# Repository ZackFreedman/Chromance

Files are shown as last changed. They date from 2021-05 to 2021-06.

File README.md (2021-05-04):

# Chromance
Big, bold rainbow-glowing wall art that features the king of shapes - the hexagon. 
This project was designed to work with an EmotiBit wristband to display biometric data, but it doesn't need one!
A gorgeous animated ripple effect will automatically kick in after just a few seconds.

Project video: https://www.youtube.com/watch?v=g6n8XLmZ__I

Instructions: https://voidstar.dozuki.com/Guide/Chromance+Assembly+Instructions/6
(PDF in the repo may be out of date)

The following information is for my configuration. Feel free to build your own - the code is very easy to edit to accommodate yours

Bill of materials:
* 10m LED channel w/ white diffuser, pref. black - https://amzn.to/3nFEC3w
* 10m DotStar LED tape, 60 pixels/m - https://www.adafruit.com/product/2239?length=4
	* OR: 10m WS2812B (NeoPixel) LED tape, 60 pixels/m - https://amzn.to/3gTGzYS
* 1x Node32S-style ESP32 module - https://amzn.to/2QO9brO
* 2.54mm headers - https://amzn.to/3ujX4S0
* 1x 8-position 2.54mm-pitch terminal - https://amzn.to/3uerfKd
* 1x 2-position 5mm-pitch terminal - https://amzn.to/3gU5WJV
* 1x 2.1mm barrel jack, PCB mount - https://amzn.to/33bmpRS
* Stripboard - https://amzn.to/3aXs2Yc
* Epoxy (I like JB Kwik-Weld) - https://amzn.to/3xHL1jp
* 5V PSU w/ 2.1mm barrel plug 5A or higher - https://amzn.to/2RkIL0A
* 1/2" wide double stick tape, at least 3m - https://amzn.to/3gT8mst
* 3D printer filament - I used carbon-fiber PLA - https://amzn.to/3xHIwh6
* Lots of wire, solder, and flux
* Hot glue

**These affiliate links support future projects and the videos about them!**

3D print list:
- 1x TopLeftNode.stl
- 1x TopRightNode.stl
- 3x TopCenterNode.stl
- 20x RegularNode.stl

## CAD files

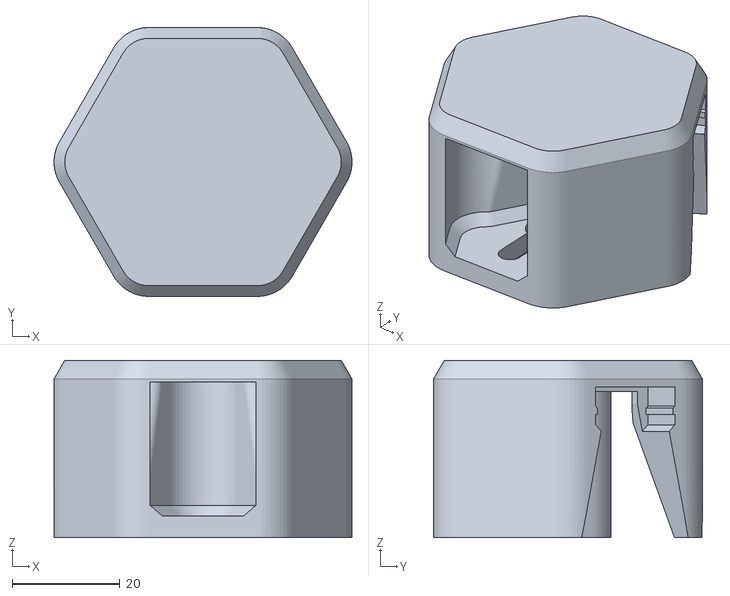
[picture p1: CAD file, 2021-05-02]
STL's/TopCenterNode.stl
55.4 x 50.0 x 33.0

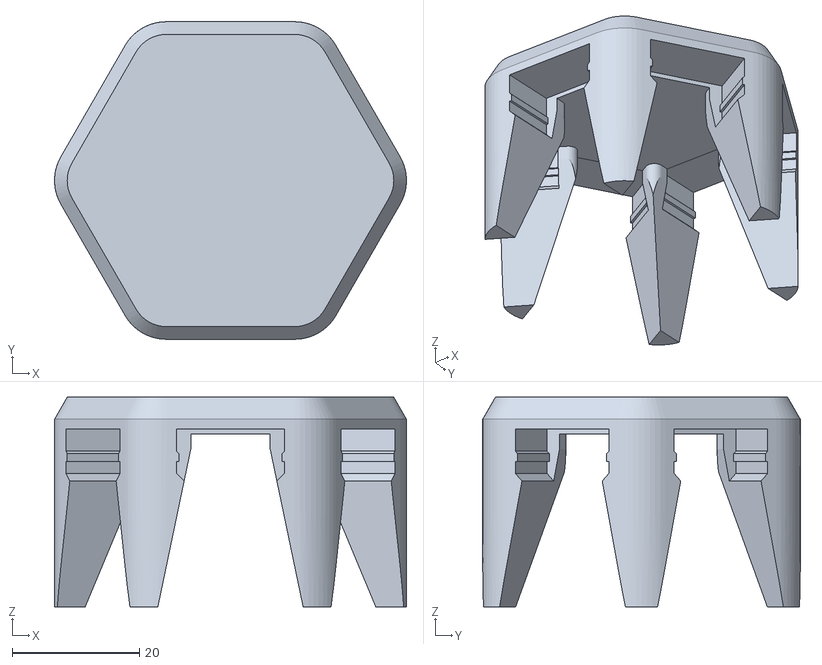
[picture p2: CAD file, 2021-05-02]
STL's/RegularNode.stl
55.4 x 50.0 x 33.0

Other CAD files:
STL's/TopLeftNode.stl
STL's/TopRightNode.stl
Models/RegularNode.f3d
Models/TopCenterNode.f3d
Models/TopLeftNode.f3d
Models/TopRightNode.f3d

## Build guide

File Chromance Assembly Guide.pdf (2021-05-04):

# Voidstar Lab

# Chromance Assembly Instructions

Build your own glowing rainbow wall hexagons - and maybe even link them with your biometrics!

## Written By: Zack Freedman

Chromance Assembly Instructions | Guide ID: 6 - Draft: 2021-05-03

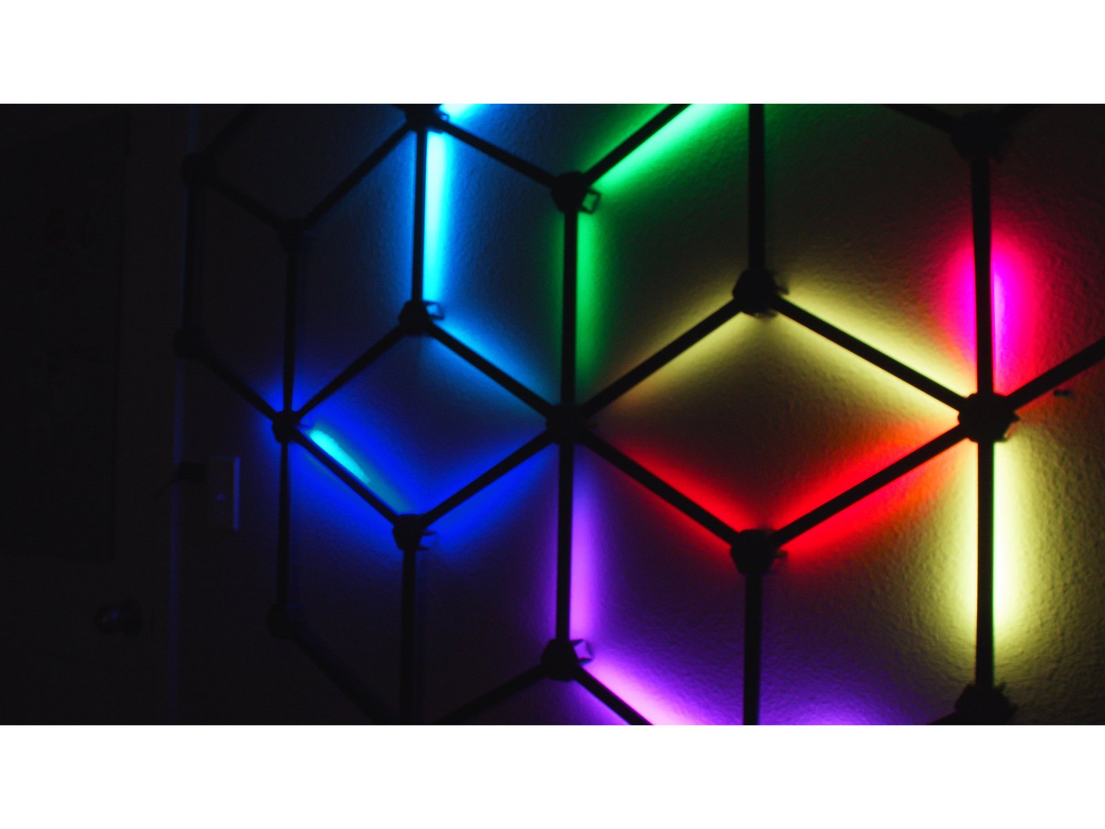
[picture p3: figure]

This document was generated on 2021-05-03 05:29:10 PM (MST).

© 2021 | voidstar.dozuki.com/ | Page 1 of 16

### INTRODUCTION

Turn your most boring wall into a big statement with this lavishly illuminated RGB decoration. It's easy to assemble and looks phenomenal - and if you have an EmotiBit, it'll even visualize your heartbeats and sweat spikes in perfectly synchronized pulses.

Watch the video: https://www.youtube.com/watch?v=g6n8XLmZ... (https://www.youtube.com/watch?v=g6n8XLmZ__I)

Download the firmware: https://github.com/ZackFreedman/Chromanc...

Grab the STL's: https://thangs.com/ZackFreedman/Chromanc...

Bill of Materials:

10m LED channel w/ white diffuser, pref. black - https://amzn.to/3nFEC3w
10m DotStar LED tape, 60 pixels/m - https://www.adafruit.com/product/2239?le... (https://www.adafruit.com/product/2239?length=4) OR: 10m WS2812B (NeoPixel) LED tape, 60 pixels/m - https://amzn.to/3gTGzYS 1x Node32S-style ESP32 module - https://amzn.to/2QO9brO
2.54mm headers - https://amzn.to/3ujX4S0
1x 8-position 2.54mm-pitch terminal - https://amzn.to/3uerfKd
1x 2-position 5mm-pitch terminal - https://amzn.to/3gU5WJV 1x 2.1mm barrel jack, PCB mount - https://amzn.to/33bmpRS Stripboard - https://amzn.to/3aXs2Yc
Epoxy (I like JB Kwik-Weld) - https://amzn.to/3xHL1jp
5V PSU w/ 2.1mm barrel plug 5A or higher - https://amzn.to/2RkIL0A1/2" wide double stick tape, at least 3m - https://amzn.to/3gT8mst
3D printer filament - I used carbon-fiber PLA - https://amzn.to/3xHIwh6 Lots of wire, solder, and flux
Hot glue

Step 1 — Start Printing

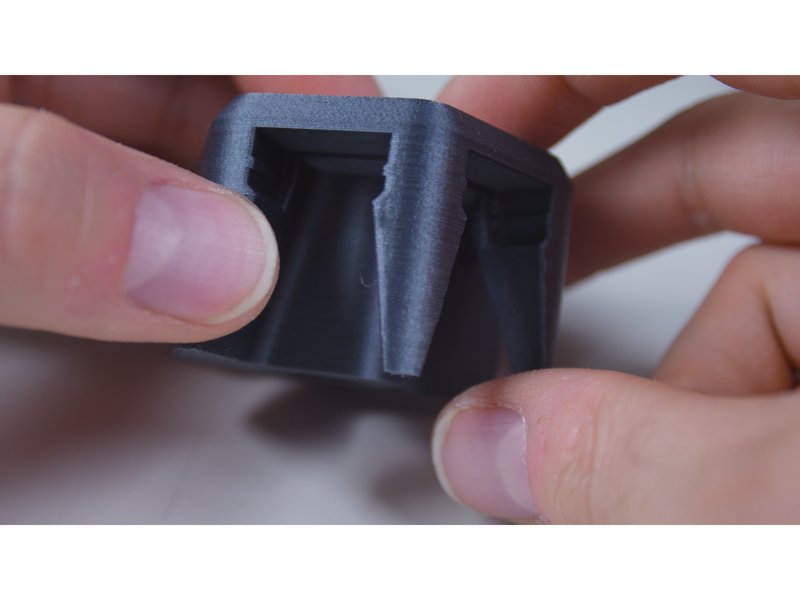
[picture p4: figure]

- Print the following:
- 1x TopLeftNode.stl
- 1x TopRightNode.stl
- 3x TopCenterNode.stl
- 20x RegularNode.stl

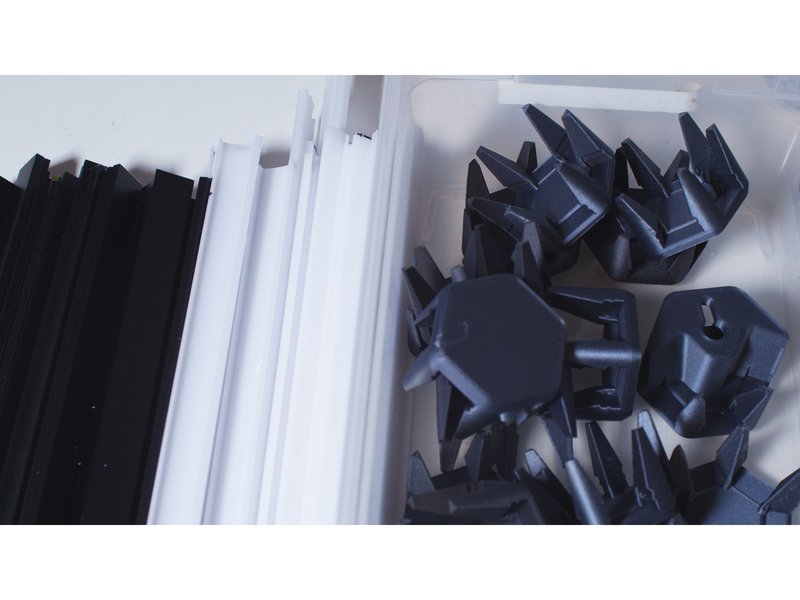
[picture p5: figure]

- I used carbon fiber PLA. Nail that first layer - it's what people will see.

The Top nodes must be printed with supports everywhere. The Regular nodes do not need supports.

Step 2 — Prep for Segments
- Cut 40 segments of LED strips, 14 LED's long.
- Don't cut off too much of the pads on the ends! We need to solder to it!

Cut 40 segments of aluminum extrusion, 25cm each. Deburr the ends so they don't cut into the strips!

- Cut 40 segments of diffuser plastic, 23cm each.

The diffusers should be shorter than the aluminum, or they'll be difficult to snap onto the extrusion after the system is assembled.

Step 3 — Assemble the Strips

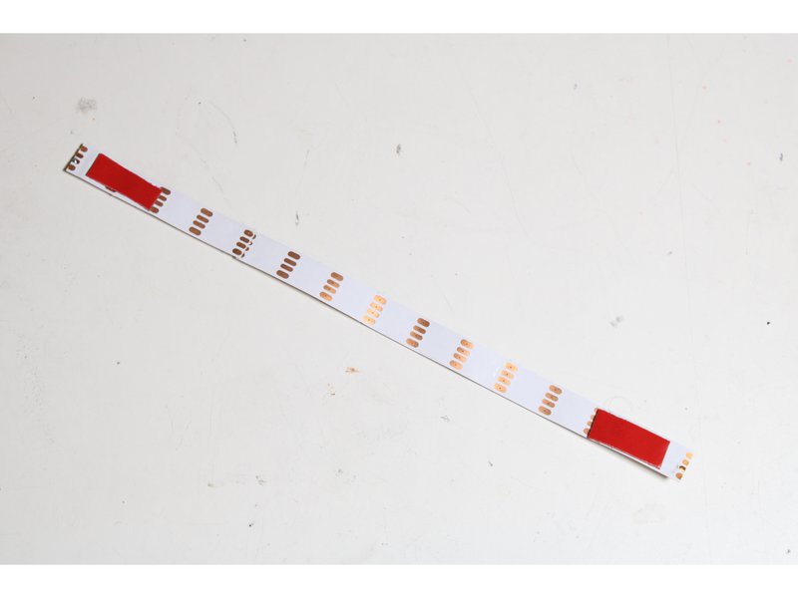
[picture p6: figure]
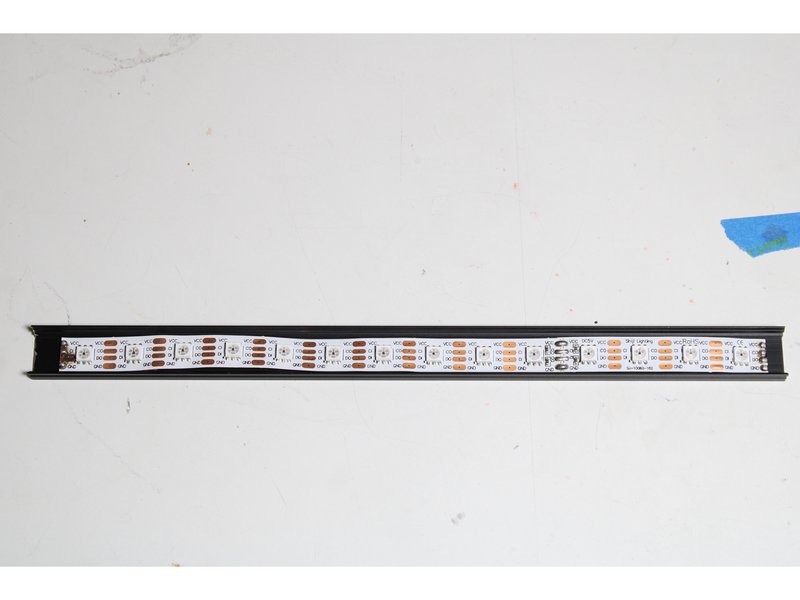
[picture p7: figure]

Use some heat-tolerant double-stick tape to mount a strip to the center of each aluminum segment.

- Don't put tape too close to the ends! It'll burn when we solder the strips!

The tape may not be necessary if your strips are particularly wide. If the channel in the extrusion holds the strip securely on its own, no tape is needed.

Step 4 — Pre-Assembly

Assemble the network - but don't glue it yet! Remember that the node names are backwards, because this is sitting upside-down.

- TopRightNode goes here.
- TopCenterNodes go here
- TopLeftNode goes here
- All other nodes are RegularNodes.

Make sure the strips face the directions indicated. There should be arrows on the strips, but if there aren't, the pads named DI and CI are the start of the strips, and DO and CO are the end.

Step 5 — Permanent Assembly

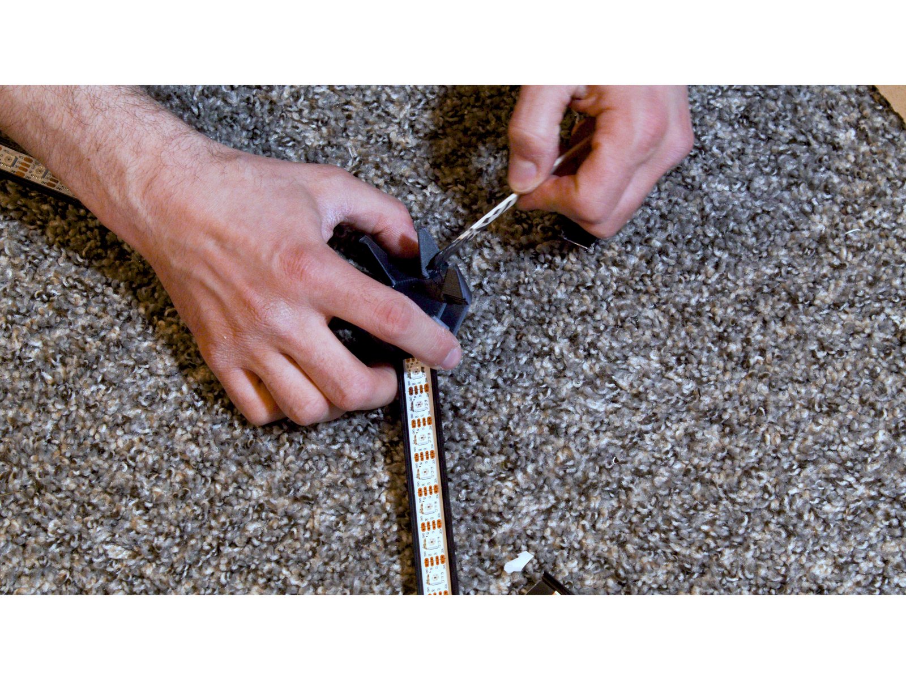
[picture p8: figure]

Before continuing, make absolutely sure that the strips and hubs are correctly oriented.

Double-check that the Top piece keyholes have the narrow bit facing up, and the circular bit facing down.

Seriously, be careful. This glue is permanent.

Mixing small batches at a time, epoxy the segments into the hubs. They should bottom out into their slots.

Ventilate the room with fresh air, and allow the epoxy to fully cure before continuing.

Step 6 — Solder Up the Strips Pt. 1
- Solder the DO pin of each strip to the DI pin of the next strip. Repeat, soldering CO to CI.
- I've indicated directions using arrows.
- NeoPixels don't have CO/CI pins.
- Due to the tutorial software's limits, the fourth strip sequence is shown in the following step.

Step 7 — Solder Up the Strips Pt. 2
- Solder up the last group of strips.

Some strips need to be connected with long wires run over other strips. Use hot glue to tack these out of the way so they don't block LED's or interfere with the diffusers.

- Solder wires to the DI pins of the first strip in each of the four sets and route them out the bottom.
- At each hub, wire all the VCC pins together.
- At each hub, wire all the GND pins together.
- Solder wires to the VCC and GND pins at the bottom node and route them out the bottom.

Step 8 — Assemble the Driver Board
- Cut a segment of stripboard 21x30 holes wide.
- Break strips as indicated.

Solder in two wire jumpers, a 2.1mm jack, two female 19-position headers, a 5mm 2-position terminal, and a 2.54mm 8-position terminal as shown.

- Solder headers to the Node32S module and mount it.

Step 9 — Configure Arduino

Open the Arduino software and open its Preferences. Add the following to the Additional Boards Manager URLs field, then restart Arduino: https://dl.espressif.com/dl/package_esp3...

- Navigate to Tools --> Board --> Boards Manager. Find 'esp32' and install it.

Navigate to Tools --> Manage Libraries. Install Adafruit_DotStar, ArduinoOSC, ESPmDNS, WiFiUdp, and ArduinoOTA.

- Plug the ESP32 module into your computer and allow any drivers to load.

DO NOT PLUG YOUR ESP32 MODULE INTO YOUR COMPUTER WHILE THE STRIPS ARE CONNECTED. IT MAY DESTROY YOUR COMPUTER.

Step 10 — Configure Software
- Select your ESP32's serial port. Pick Tools --> Board --> ESP32 Arduino --> Node32s.

Open the firmware. Change the SSID, password, Gateway, and Subnet to fit your router configuration. Pick an IP address that's unused, preferably outside your router's DHCP range. Pick a recv_port, ideally above 16000.

- Upload the firmware. Allow the ESP32 to reboot and connect to the network.

Go to Tools --> Port and look for a Network Port. If you see your selected IP address, you're ready for OTA updates! Your USB cable is no longer necessary.

- If you don't see your device, I dunno. Ask on the Voidstar Lab Discord!

Step 11 — Wire it Up

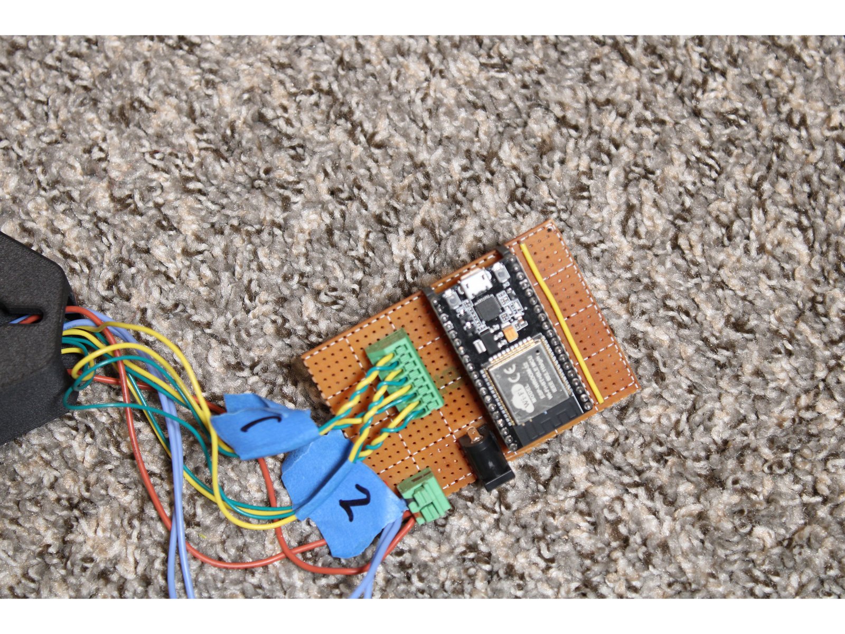
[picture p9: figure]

Connect the DIN and CIN pins to the appropriate terminals.

Strip 1 (marked with blue arrows in previous diagrams) goes in the terminals furthest from the jack.

- Strip 2 (marked green) is next
- Then Strip 3 (marked yellow)
- Finally, Strip 4 (marked black)

The DIN lines are further from the jack (yellow wires in my picture) and CIN lines are closer.

Put the VCC wires into the left 5mm terminal, and the GND wires into the right.

Plug in the PSU and plug it into the jack. If your project catches fire, you've made a mistake.

Step 12 — Testing Time

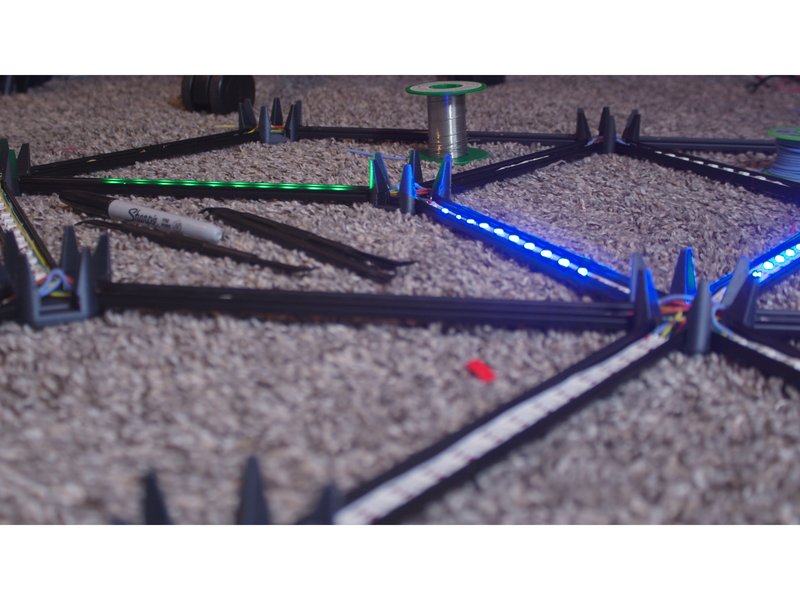
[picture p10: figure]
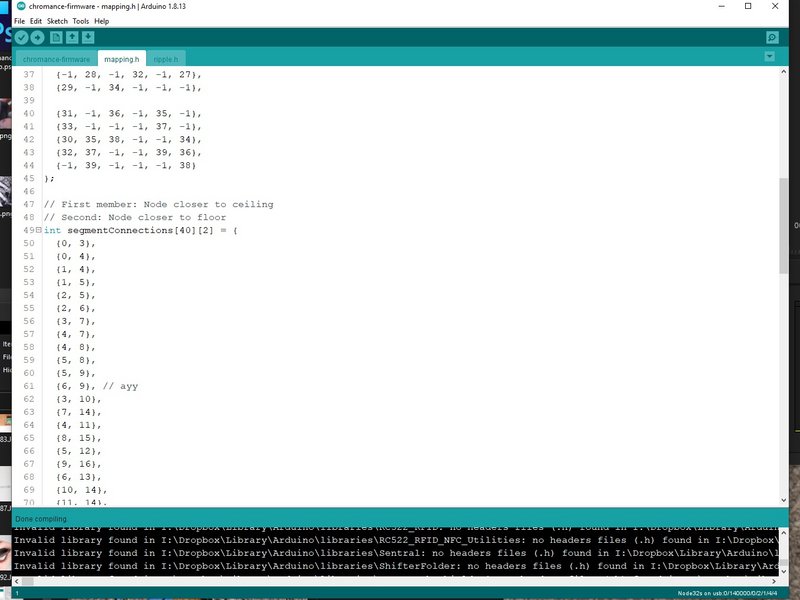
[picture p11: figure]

- Watch the ripples. They should begin after a few seconds and proceed smoothly through all strips.

If one or more strips fails to light up, check for shorts, breaks, and boo-boos. Pads can get ripped off very easily - in that case, remove and replace that strip.

If a ripple jumps around on a specific strip, it may be backwards. Adjust mapping.h to reverse it. The nodes and strips are numbered right to left, top to bottom.

Step 13 — Configure the EmotiBit
- An EmotiBit is not necessary to use the Chromance, but it makes it way cooler!
- Assemble, charge, and configure your EmotiBit as instructed by the manufacturer.
- Download, install, and open the EmotiBit Oscilloscope. Then close it!

Open C:\Program Files\EmotiBit\EmotiBit Oscilloscope\data\oscOutputSettings.xml (or whatever it is on Linux or Mac). Edit the <output> section to match the IP address and port you put in the firmware earlier.

- Connect your EmotiBit, and enable OSC in the Output List.

Step 14 — You're Done!
- Put your EmotiBit on and ensure data is streaming through the Oscilloscope
- Your heartbeats and EDA changes should immediately start firing ripples through the Chromance!
- Adjust the biometric settings in the firmware to respond accurately to your emotional state.
- Set up a chair, smoke a fat (legal in Colorado) doobie, and enjoy the show.

If you enjoyed the project and want to support the next one, head to patreon.com/zackfreedman and give me a huge pile of money!

- You rule.

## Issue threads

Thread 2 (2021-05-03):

BOM is missing the LEDs

ztaylor54, 2021-05-03:
I know you gave two options in the video, DotStar and NeoPixel, but neither are listed in the README's BOM

ZackFreedman, 2021-05-03:
Good eye. I've added both.

Closed 2021-05-03.

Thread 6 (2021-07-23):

What is the total size in dimentions?

nobels, 2021-07-23:
Hello,

I wonder if you just can share the size in dimentions :-)

Before I like to build this, i would like to know if this fits on my wall. (or ceiling)

Thanks

aaronse, 2021-07-23:
Guessing ~1.2m wide by ~1m high for current checked in code and build instructions, with hex arrangement of 23cm lengths.  However, people can customize the graph node-edge definitions in mapping.h to other dimensions and layouts to fit their chromance desires.

Would be interesting to see alternative mappings and layouts people end up building.

nobels, 2021-08-05:
That is the plan ... but i would like to start with yours ;-)

Closed 2021-08-05.

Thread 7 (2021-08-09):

ArduinoOSC Library

maxmoq, 2021-08-09:
in chromance-firmware.ino use #include <ArduinoOSCWifi.h> instead. Fixes the compilation issue

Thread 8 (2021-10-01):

Set Ripples to select color from set list

TomWaterz, 2021-10-01:
Can someone help me figure out how to generate ripple colors from a set array of color values? I've tried doing it but can't seem to figure out how the color wheel works.

I have something like this

char colorOptions[3] = {'#FFA233', '#DC0000', '#8F00AB'};

and just want each ripple to randomly choose a color from this array.

EasyAsABC123, 2023-02-08:
Here are the code locations where colors are chosen:
[randomPulse color generation](https://github.com/ZackFreedman/Chromance/blob/main/chromance-firmware/chromance-firmware.ino#L349)
[cubePulse color selection](https://github.com/ZackFreedman/Chromance/blob/main/chromance-firmware/chromance-firmware.ino#L380)
[starburst color selection](https://github.com/ZackFreedman/Chromance/blob/main/chromance-firmware/chromance-firmware.ino#L404)

These all rely on `baseColor`, which is randomly generated on [this line](https://github.com/ZackFreedman/Chromance/blob/main/chromance-firmware/chromance-firmware.ino#L286)

If you switch out `baseColor` with a random selection from your array this should "work".
```c++
unsigned int baseColor = colorOptions[random(NUMBER_OF_COLORS)];
```

Minor correction to your array declaration:
```c++
    const int NUMBER_OF_COLORS = 3;
    const char* colorOptions[] = {'#FFA233', '#DC0000', '#8F00AB'};
```

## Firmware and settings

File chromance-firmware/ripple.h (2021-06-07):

/*
   A dot animation that travels along rails
   (C) Voidstar Lab LLC 2021
*/

#ifndef RIPPLE_H_
#define RIPPLE_H_

// WARNING: These slow things down enough to affect performance. Don't turn on unless you need them!
//#define DEBUG_ADVANCEMENT  // Print debug messages about ripples' movement
//#define DEBUG_RENDERING  // Print debug messages about translating logical to actual position

#include <Adafruit_DotStar.h>
#include "mapping.h"

enum rippleState {
  dead,
  withinNode,  // Ripple isn't drawn as it passes through a node to keep the speed consistent
  travelingUpwards,
  travelingDownwards
};

enum rippleBehavior {
  weaksauce = 0,
  feisty = 1,
  angry = 2,
  alwaysTurnsRight = 3,
  alwaysTurnsLeft = 4
};

float fmap(float x, float in_min, float in_max, float out_min, float out_max) {
  return (x - in_min) * (out_max - out_min) / (in_max - in_min) + out_min;
}

class Ripple {
  public:
    Ripple(int id) : rippleId(id) {
      Serial.print("Instanced ripple #");
      Serial.println(rippleId);
    }

    rippleState state = dead;
    unsigned long color;

    /*
       If within a node: 0 is node, 1 is direction
       If traveling, 0 is segment, 1 is LED position from bottom
    */
    int position[2];

    // Place the Ripple in a node
    void start(byte n, byte d, unsigned long c, float s, unsigned long l, byte b) {
      color = c;
      speed = s;
      lifespan = l;
      behavior = b;

      birthday = millis();
      pressure = 0;
      state = withinNode;

      position[0] = n;
      position[1] = d;

      justStarted = true;

      Serial.print("Ripple ");
      Serial.print(rippleId);
      Serial.print(" starting at node ");
      Serial.print(position[0]);
      Serial.print(" direction ");
      Serial.println(position[1]);
    }

    void advance(byte ledColors[40][14][3]) {
      unsigned long age = millis() - birthday;

      if (state == dead)
        return;

      pressure += fmap(float(age), 0.0, float(lifespan), speed, 0.0);  // Ripple slows down as it ages
      // TODO: Motion of ripple is severely affected by loop speed. Make it time invariant

      if (pressure < 1 && (state == travelingUpwards || state == travelingDownwards)) {
        // Ripple is visible but hasn't moved - render it to avoid flickering
        renderLed(ledColors, age);
      }

      while (pressure >= 1) {
#ifdef DEBUG_ADVANCEMENT
        Serial.print("Ripple ");
        Serial.print(rippleId);
        Serial.println(" advancing:");
#endif

        switch (state) {
          case withinNode: {
              if (justStarted) {
                justStarted = false;
              }
              else {
#ifdef DEBUG_ADVANCEMENT
                Serial.print("  Picking direction out of node ");
                Serial.print(position[0]);
                Serial.print(" with agr. ");
                Serial.println(behavior);
#endif

                int newDirection = -1;

                int sharpLeft = (position[1] + 1) % 6;
                int wideLeft = (position[1] + 2) % 6;
                int forward = (position[1] + 3) % 6;
                int wideRight = (position[1] + 4) % 6;
                int sharpRight = (position[1] + 5) % 6;

                if (behavior <= 2) {  // Semi-random aggressive turn mode
                  // The more aggressive a ripple, the tighter turns it wants to make.
                  // If there aren't any segments it can turn to, we need to adjust its behavior.
                  byte anger = behavior;

                  while (newDirection < 0) {
                    if (anger == 0) {
                      int forwardConnection = nodeConnections[position[0]][forward];

                      if (forwardConnection < 0) {
                        // We can't go straight ahead - we need to take a more aggressive angle
#ifdef DEBUG_ADVANCEMENT
                        Serial.println("  Can't go straight - picking more agr. path");
#endif
                        anger++;
                      }
                      else {
#ifdef DEBUG_ADVANCEMENT
                        Serial.println("  Going forward");
#endif
                        newDirection = forward;
                      }
                    }

                    if (anger == 1) {
                      int leftConnection = nodeConnections[position[0]][wideLeft];
                      int rightConnection = nodeConnections[position[0]][wideRight];

                      if (leftConnection >= 0 && rightConnection >= 0) {
#ifdef DEBUG_ADVANCEMENT
                        Serial.println("  Turning left or right at random");
#endif
                        newDirection = random(2) ? wideLeft : wideRight;
                      }
                      else if (leftConnection >= 0) {
#ifdef DEBUG_ADVANCEMENT
                        Serial.println("  Can only turn left");
#endif
                        newDirection = wideLeft;
                      }
                      else if (rightConnection >= 0) {
#ifdef DEBUG_ADVANCEMENT
                        Serial.println("  Can only turn right");
#endif
                        newDirection = wideRight;
                      }
                      else {
#ifdef DEBUG_ADVANCEMENT
                        Serial.println("  Can't make wide turn - picking more agr. path");
#endif
                        anger++;  // Can't take shallow turn - must become more aggressive
                      }
                    }

                    if (anger == 2) {
                      int leftConnection = nodeConnections[position[0]][sharpLeft];
                      int rightConnection = nodeConnections[position[0]][sharpRight];

                      if (leftConnection >= 0 && rightConnection >= 0) {
#ifdef DEBUG_ADVANCEMENT
                        Serial.println("  Turning left or right at random");
#endif
                        newDirection = random(2) ? sharpLeft : sharpRight;
                      }
                      else if (leftConnection >= 0) {
#ifdef DEBUG_ADVANCEMENT
                        Serial.println("  Can only turn left");
#endif
                        newDirection = sharpLeft;
                      }
                      else if (rightConnection >= 0) {
#ifdef DEBUG_ADVANCEMENT
                        Serial.println("  Can only turn right");
#endif
                        newDirection = sharpRight;
                      }
                      else {
#ifdef DEBUG_ADVANCEMENT
                        Serial.println("  Can't make tight turn - picking less agr. path");
#endif
                        anger--;  // Can't take tight turn - must become less aggressive
                      }
                    }
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

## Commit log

2021-05-03 Added LED's to BOM
2021-05-04 Added assembly guide
2021-05-14 reconstruct Fusion360 model of regular node
    [RegularNode.f3d]
